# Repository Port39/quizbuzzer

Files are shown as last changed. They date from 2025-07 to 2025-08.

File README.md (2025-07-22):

# Simple quiz buzzer

Features:
- Four/six inputs for buttons.
- Five/eight open collector outputs to trigger external periphery.
- 7 segment
- Powered by an ATmegaXY8(P) (e.g., an Atmega328, or even an ATmega48)

## Building and flashing the firmware

You need AVR-GCC or something compatible to build this.
Just run `make` and then `make flash`.
The latter comand uses *avrdude* to flash your µC.
You _should_ be able to build the firmware with ~~Atmel~~ Microchip Studio as well.
Set the variables of the makefile accordingly:

- `MCU` (`atmega328p`): Set to your variant of the uC (e.g., if you have an ATmega168, set it to `atmega168`)
- `F_CPU` (`1000000`): The CPU speed your controller runs at. This does not set the actual CPU speed (set fuses for that!), but just tells the compiler. Currently only `1000000` and `16000000` are supported yet.
- `PORT` (`/dev/ttyUSB0`): The port your programmer is connected to.
- `PROGRAMMER` (`arduino`): The programmer you use (see below for some common configurations)
- `BAUD` (`9600`): The baud rate of the programmer.

### Programmer and baud rate combinations

- "Arduino as ISP": `PROGRAMMER=stk500v1`, `BAUD=19200`
- USB bootloader from the Arduino project: `PROGRAMMER=arduino`, `BAUD=9600`
- "mySmartUSB light" in stk500 mode: `PROGRAMMER=stk500`, `BAUD=115200`

## Schematics

Schematics are made with KiCad.
Only standard components were used (or the used footprint is embedded).

## Revisions

The firmware is not compatible between board revisions.

### Revision 1

Revision 1 is for building on a 7x9cm prototyping board.

Depending on the pinout of your 7-segment display, you may need to change the array in *7segment.c*.

### Revision 2

Revision 2 (planned) is for soldering an manufactured PCB.
The serial (UART) outputs are available for programming (if a bootloader is flashed),
and output the current game state.

The second revision has the following upgrades:
- A CH340 on the board. This allows serial communication and programming over USB!
- Thanks to multiplexers, up to six players can play now!
- And an additional open collector "buzzer" pin is added. This allows for external buzzers circuits.
- There now is a power on LED.

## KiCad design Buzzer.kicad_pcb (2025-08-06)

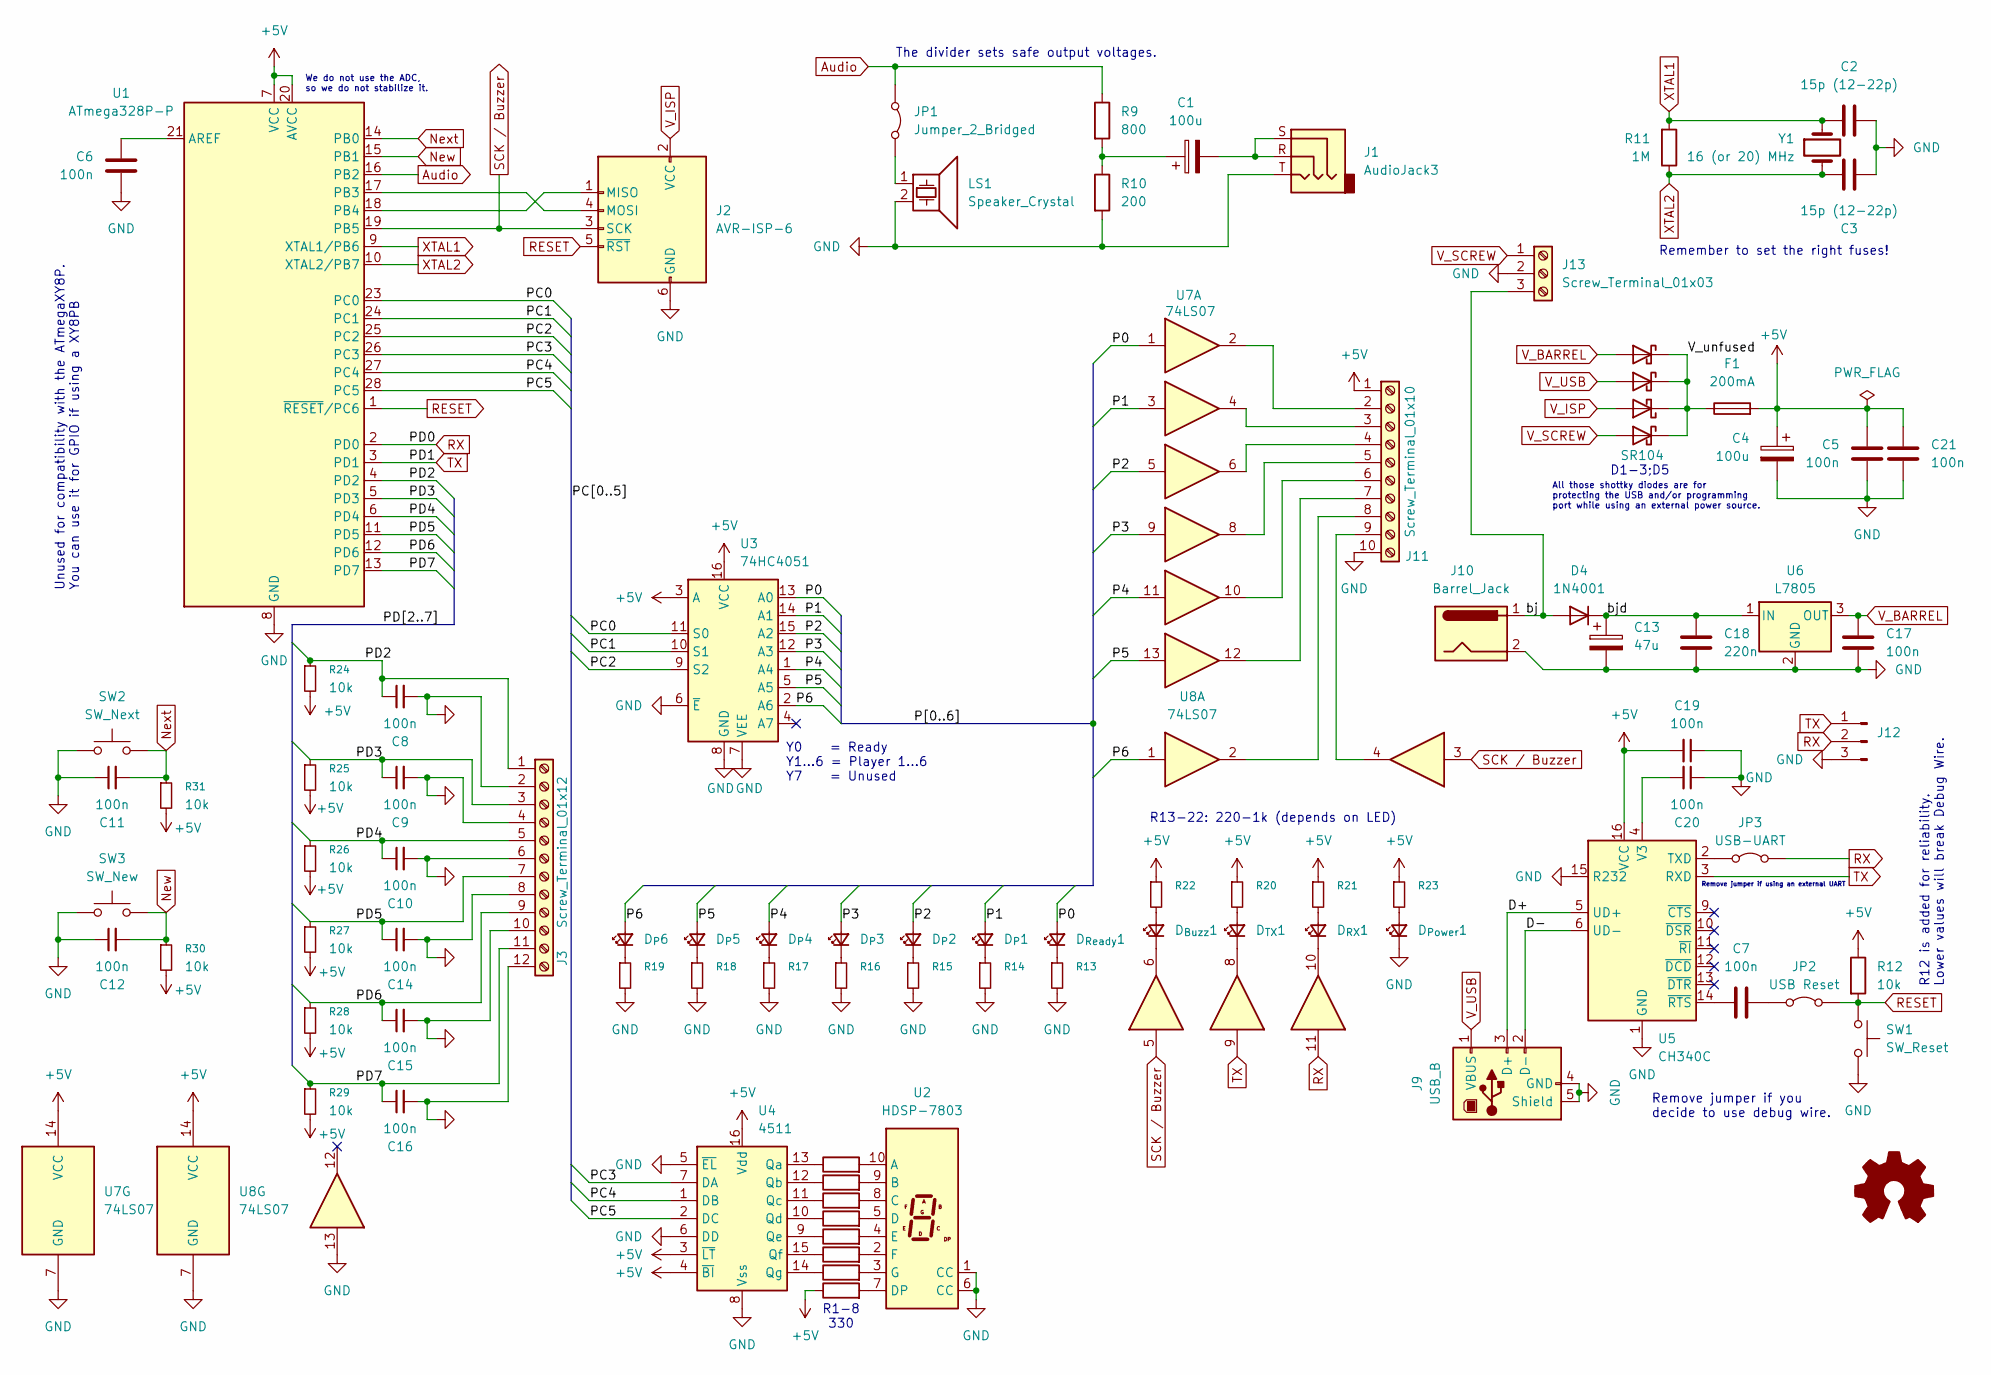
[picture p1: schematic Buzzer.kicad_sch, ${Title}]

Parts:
C1, C4: 100u; CP_Radial_D6.3mm_P2.50mm
C2, C3: 15p (12-22p); C_Disc_D5.0mm_W2.5mm_P5.00mm
C5, C6, C7, C8, C9, C10, C11, C12, C14, C15, C16, C17, C19, C20, C21: 100n; C_Disc_D5.0mm_W2.5mm_P2.50mm
C13: 47u; CP_Radial_D8.0mm_P3.50mm
C18: 220n; C_Disc_D5.0mm_W2.5mm_P2.50mm
D1, D2, D5: SR104; D_DO-41_SOD81_P7.62mm_Horizontal
D3: SR104; D_DO-41_SOD81_P12.70mm_Horizontal
D4: 1N4001; D_DO-41_SOD81_P7.62mm_Horizontal
D_{Buzz}1: LED_Small; LED_Rectangular_W5.0mm_H2.0mm
D_{Power}1: LED_Small; LED_Rectangular_W5.0mm_H2.0mm
D_{P}1, D_{P}2, D_{P}3, D_{P}4, D_{P}5, D_{P}6: LED_Small; LED_Rectangular_W5.0mm_H2.0mm
D_{RX}1: LED_Small; LED_Rectangular_W5.0mm_H2.0mm
D_{Ready}1: LED_Small; LED_Rectangular_W5.0mm_H2.0mm
D_{TX}1: LED_Small; LED_Rectangular_W5.0mm_H2.0mm
F1: 200mA; Fuseholder_Littelfuse_100_series_5x20mm
J1: AudioJack3; Jack_3.5mm_Ledino_KB3SPRS_Horizontal
J2: AVR-ISP-6; IDC-Header_2x03_P2.54mm_Vertical
J3: Screw_Terminal_01x12; TerminalBlock_Phoenix_MKDS-1,5-12-5.08_1x12_P5.08mm_Horizon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
J9: USB_B; USB_B_OST_USB-B1HSxx_Horizontal
J10: Barrel_Jack; BarrelJack_Kycon_KLDX-0202-xC_Horizontal
J11: Screw_Terminal_01x10; TerminalBlock_Phoenix_MKDS-1,5-10-5.08_1x10_P5.08mm_Horizon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
J12: Conn_01x03_Pin; PinHeader_1x03_P2.54mm_Vertical
J13: Screw_Terminal_01x03; TerminalBlock_Phoenix_MKDS-1,5-3-5.08_1x03_P5.08mm_Horizont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
JP1: Jumper_2_Bridged; PinHeader_1x03_P2.54mm_Vertical
JP2: USB Reset; PinHeader_1x03_P2.54mm_Vertical
JP3: USB-UART; PinHeader_1x03_P2.54mm_Vertical
LS1: Speaker_Crystal; PinHeader_1x02_P2.54mm_Vertical
R1, R2, R3, R4, R5, R6, R7, R8: 330; R_Axial_DIN0207_L6.3mm_D2.5mm_P10.16mm_Horizontal
R9: 800; R_Axial_DIN0207_L6.3mm_D2.5mm_P10.16mm_Horizontal
R10: 200; R_Axial_DIN0207_L6.3mm_D2.5mm_P10.16mm_Horizontal
R11: 1M; R_Axial_DIN0207_L6.3mm_D2.5mm_P10.16mm_Horizontal
R12, R25, R28, R30, R31: 10k; R_Axial_DIN0207_L6.3mm_D2.5mm_P10.16mm_Horizontal
R13, R14, R15, R16, R17, R18, R19, R20, R21, R22, R23: 220-1k; R_Axial_DIN0207_L6.3mm_D2.5mm_P10.16mm_Horizontal
R24, R29: 10k; R_Axial_DIN0207_L6.3mm_D2.5mm_P7.62mm_Horizontal
R26, R27: 10k; R_Axial_DIN0207_L6.3mm_D2.5mm_P15.24mm_Horizontal
SW1: SW_Reset; SW_PUSH_6mm
SW2: SW_Next; SW_PUSH_6mm
SW3: SW_New; SW_PUSH_6mm
U1: ATmega328P-P; DIP-28_W7.62mm_Socket
U2: HDSP-7803; HDSP-7801
U3: 74HC4051; DIP-16_W7.62mm_Socket
U4: 4511; DIP-16_W7.62mm_Socket
U5: CH340C; SOIC-16_3.9x9.9mm_P1.27mm
U6: L7805; TO-220-3_Horizontal_TabDown
U7, U8: 74LS07; DIP-14_W7.62mm_Socket
Y1: 16 (or 20) MHz; Crystal_HC49-U_Vertical

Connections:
+5V: C4.1, C5.2, C19.2, C21.2, F1.2, J11.1, R8.1, R12.1, R20.1, R21.1, R22.1, R23.1, R24.2, R25.2, R26.2, R27.2, R28.2, R29.2, R30.2, R31.2, U1.7 (VCC), U1.20 (AVCC), U3.3 (A), U3.16 (VCC), U4.3 (~LT), U4.4 (~BI), U4.16 (Vdd), U5.16 (VCC), U7.14 (VCC), U8.14 (VCC)
/D+: J9.3 (D+), U5.5 (UD+)
/D-: J9.2 (D-), U5.6 (UD-)
/P0: D_{Ready}1.2 (A), U3.13 (A0), U7.1
/P1: D_{P}1.2 (A), U3.14 (A1), U7.3
/P2: D_{P}2.2 (A), U3.15 (A2), U7.5
/P3: D_{P}3.2 (A), U3.12 (A3), U7.9
/P4: D_{P}4.2 (A), U3.1 (A4), U7.11
/P5: D_{P}5.2 (A), U3.5 (A5), U7.13
/P6: D_{P}6.2 (A), U3.2 (A6), U8.1
/PC0: U1.23 (PC0), U3.11 (S0)
/PC1: U1.24 (PC1), U3.10 (S1)
/PC2: U1.25 (PC2), U3.9 (S2)
/PC3: U1.26 (PC3), U4.7 (DA)
/PC4: U1.27 (PC4), U4.1 (DB)
/PC5: U1.28 (PC5), U4.2 (DC)
/PD2: C8.1, J3.1, R24.1, U1.4 (PD2)
/PD3: C9.1, J3.3, R25.1, U1.5 (PD3)
/PD4: C10.1, J3.5, R26.1, U1.6 (PD4)
/PD5: C14.1, J3.7, R27.1, U1.11 (PD5)
/PD6: C15.1, J3.9, R28.1, U1.12 (PD6)
/PD7: C16.1, J3.11, R29.1, U1.13 (PD7)
/V_unfused: D1.1 (K), D2.1 (K), D3.1 (K), D5.1 (K), F1.1
/bj: D4.2 (A), J10.1, J13.3
/bjd: C13.1, C18.1, D4.1 (K), U6.1 (IN)
Audio: JP1.1 (A), R9.1, U1.16 (PB2)
GND: C2.2, C3.2, C4.2, C5.1, C6.1, C8.2, C9.2, C10.2, C11.1, C12.1, C13.2, C14.2, C15.2, C16.2, C17.2, C18.2, C19.1, C20.1, C21.1, D_{Power}1.1 (K), J1.T, J2.6 (GND), J3.2, J3.4, J3.6, J3.8, J3.10, J3.12, J9.4 (GND), J9.5 (Shield), J10.2, J11.10, J12.3, J13.2, LS1.2, R10.2, R13.2, R14.2, R15.2, R16.2, R17.2, R18.2, R19.2, SW1.2, SW2.1, SW3.1, U1.8 (GND), U1.22 (GND), U2.1 (CC), U2.6 (CC), U3.6 (~E), U3.7 (VEE), U3.8 (GND), U4.5 (~EL), U4.6 (DD), U4.8 (Vss), U5.1 (GND), U5.15 (R232), U6.2 (GND), U7.7 (GND), U8.7 (GND), U8.13
unnamed: C1.1, R9.2, R10.1
unnamed: C1.2, J1.R, J1.S
unnamed: D_{Buzz}1.2 (A), R22.2
unnamed: D_{Buzz}1.1 (K), U8.6
unnamed: D_{Power}1.2 (A), R23.2
unnamed: D_{P}1.1 (K), R14.1
unnamed: D_{P}2.1 (K), R15.1
unnamed: D_{P}3.1 (K), R16.1
unnamed: D_{P}4.1 (K), R17.1
unnamed: D_{P}5.1 (K), R18.1
unnamed: D_{P}6.1 (K), R19.1
unnamed: D_{RX}1.2 (A), R21.2
unnamed: D_{RX}1.1 (K), U8.10
unnamed: D_{Ready}1.1 (K), R13.1
unnamed: D_{TX}1.2 (A), R20.2
unnamed: D_{TX}1.1 (K), U8.8
unnamed: J2.1 (MISO), U1.18 (PB4)
unnamed: J2.4 (MOSI), U1.17 (PB3)
unnamed: J11.2, U7.2
unnamed: J11.3, U7.4
unnamed: J11.4, U7.6
unnamed: J11.5, U7.8
unnamed: J11.6, U7.10
unnamed: J11.7, U7.12
unnamed: J11.8, U8.2
unnamed: J11.9, U8.4
unnamed: JP1.2 (B), LS1.1
unnamed: C7.2, JP2.1 (A)
unnamed: JP3.1 (A), U5.2 (TXD)
unnamed: C6.2, U1.21 (AREF)
unnamed: R1.2, U2.10 (A)
unnamed: R2.2, U2.9 (B)
unnamed: R3.2, U2.8 (C)
unnamed: R4.2, U2.5 (D)
unnamed: R8.2, U2.7 (DP)
unnamed: R5.2, U2.4 (E)
unnamed: R6.2, U2.2 (F)
unnamed: R7.2, U2.3 (G)
unnamed: R1.1, U4.13 (Qa)
unnamed: R2.1, U4.12 (Qb)
unnamed: R3.1, U4.11 (Qc)
unnamed: R4.1, U4.10 (Qd)
unnamed: R5.1, U4.9 (Qe)
unnamed: R6.1, U4.15 (Qf)
unnamed: R7.1, U4.14 (Qg)
unnamed: C20.2, U5.4 (V3)
unnamed: C7.1, U5.14 (~RTS)
New: C12.2, R30.1, SW3.2, U1.15 (PB1)
Next: C11.2, R31.1, SW2.2, U1.14 (PB0)
RESET: J2.5 (~RST), JP2.2 (B), R12.2, SW1.1, U1.1 (~RESET/PC6)
RX: J12.2, JP3.2 (B), U1.2 (PD0), U8.11
SCK / Buzzer: J2.3 (SCK), U1.19 (PB5), U8.3, U8.5
TX: J12.1, U1.3 (PD1), U5.3 (RXD), U8.9
V_BARREL: C17.1, D1.2 (A), U6.3 (OUT)
V_ISP: D3.2 (A), J2.2 (VCC)
V_SCREW: D5.2 (A), J13.1
V_USB: D2.2 (A), J9.1 (VBUS)
XTAL1: C2.1, R11.2, U1.9 (XTAL1/PB6), Y1.1
XTAL2: C3.1, R11.1, U1.10 (XTAL2/PB7), Y1.2

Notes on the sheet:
D1-3;D5
R1-8 330
We do not use the ADC, so we do not stabilize it.
Y0 = Ready Y1...6 = Player 1...6 Y7 = Unused
Remember to set the right fuses!
All those shottky diodes are for protecting the USB and/or programming port while using an external power source.
R12 is added for reliability. Lower values will break Debug Wire.
Remove jumper if you decide to use debug wire.
The divider sets safe output voltages.
R13-22: 220-1k (depends on LED)
Unused for compatibility with the ATmegaXY8P. You can use it for GPIO if using a XY8PB
Remove jumper if using an external UART

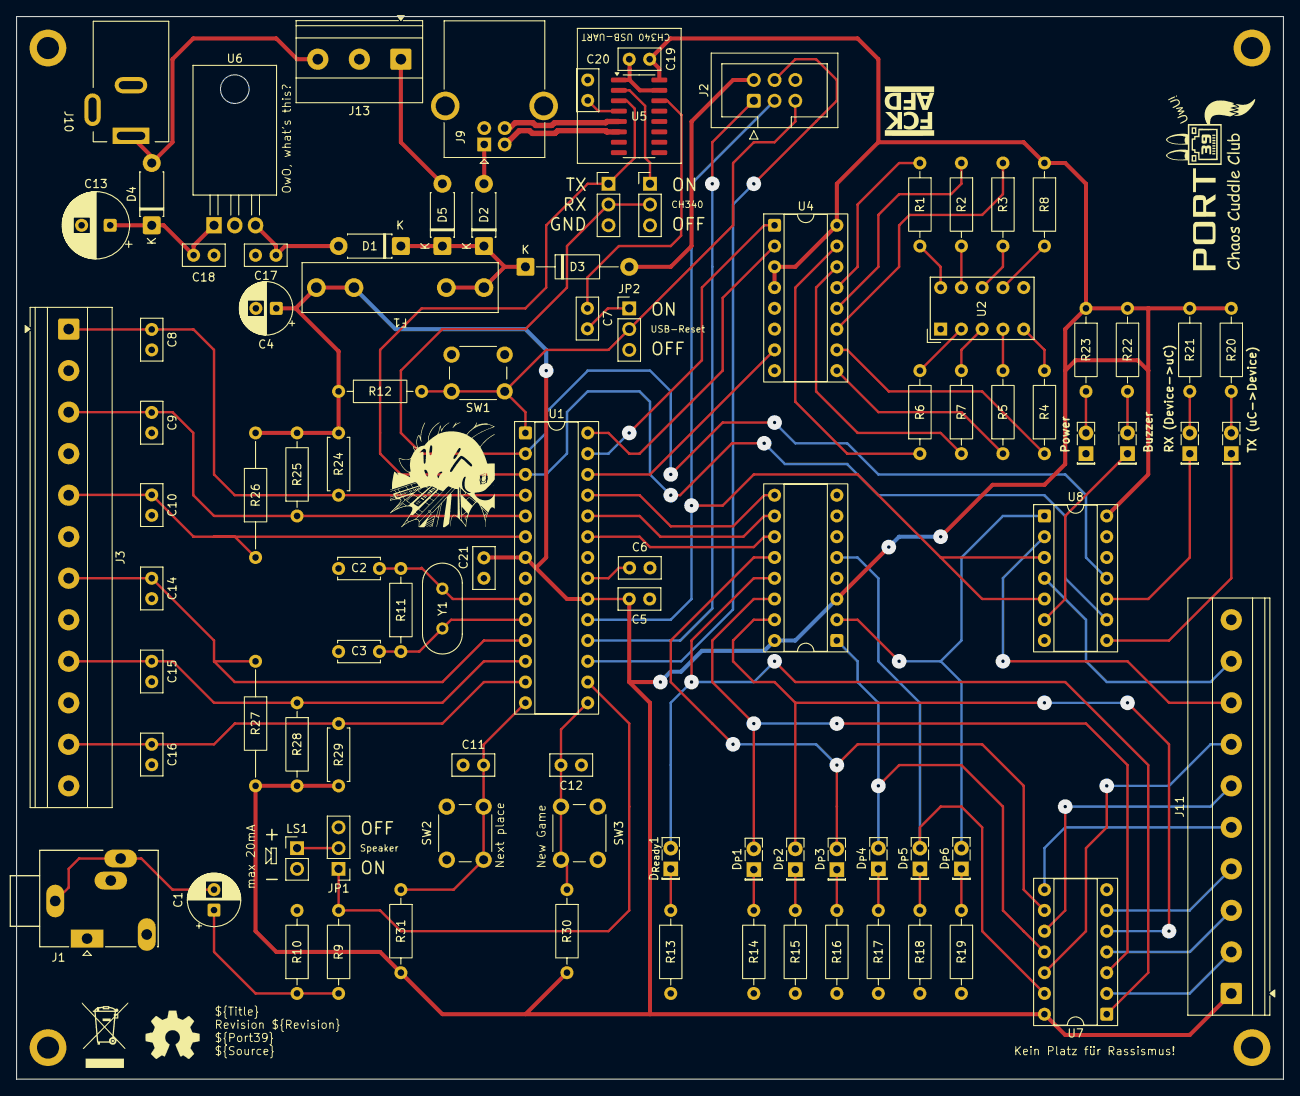
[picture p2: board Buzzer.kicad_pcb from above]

Board: 2 copper layers, 155.0 x 130.0 mm, 93 parts (0 on the bottom side), 86 nets.

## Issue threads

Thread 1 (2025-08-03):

Ideas for revision 3

Varbin, 2025-08-03:
- Replace the 7805 with a switching regulator such as the LM2574-5.0
- Switch to SMD components. This adds 4 pins on the ATmega328P**B**
- This allows adding e.g. I²C for more diverse extensions
- Make a daisy-chaining connector for light and buttons.
- Use a 4 layer board to make layouting 5V/GND easier.

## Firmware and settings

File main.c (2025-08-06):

// SPDX-License-Identifier: 
// Copyright (c) 2025 Simon Biewald
//
//

#include "board.h"
#include "logic.h"
#include "uart.h"

int main(void) {
    setupHardware();
#ifdef SERIAL
    init_serial();
#endif
    newGame();

    // This is an event (interrupt) based program.
    // The following loop prevents the controller from halting.
    for (;;);
}

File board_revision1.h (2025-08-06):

#ifndef BUZZER_BOARD_REVISION1_H
#define BUZZER_BOARD_REVISION1_H

// Pin definitions for the 7-segment display.
#define SEGMENT_A (1 << PIN2)
#define SEGMENT_B (1 << PIN3)
#define SEGMENT_C (1 << PIN6)
#define SEGMENT_D (1 << PIN7)
#define SEGMENT_E (1 << PIN4)
#define SEGMENT_F (1 << PIN1)
#define SEGMENT_G (1 << PIN0)
// Comment out for common cathode display
#define INVERT_SEGMENTS

#endif

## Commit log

2025-06-25 Initial commit.
    [Buzzer.kicad_pcb, Buzzer.kicad_sch]
2025-07-22 Add revision 2 circuit, pcb and documentation.
    [Buzzer.kicad_pcb, Buzzer.kicad_sch]
2025-07-22 Add gerber files.
2025-08-06 Set schematic revisions by variables.
    [Buzzer.kicad_pcb, Buzzer.kicad_sch]
2025-08-06 Restructure code to be compatible with both board revisions.

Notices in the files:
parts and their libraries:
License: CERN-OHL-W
